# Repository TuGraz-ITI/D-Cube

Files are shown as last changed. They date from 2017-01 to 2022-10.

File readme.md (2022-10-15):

# D-Cube Benchmark #
The entire software stack for the ([public D-Cube instance](https://iti-testbed.tugraz.at/overview)) has been released as open-source as well and can be found ([here](https://github.com/TuGraz-ITI/D-Cube-Benchmark)). The initial documentation of the stack is avaialble ([here](https://tugraz-iti.github.io)).

# D-Cube Design #

D-Cube is published as open source hardware under [CC-BY-SA](license.md) ([online](https://creativecommons.org/licenses/by-sa/4.0/deed.en)).
D-Cube is a low-cost tool that allows to accurately profile the end-to-end delay, reliability, and power consumption, of low-power wireless sensor nodes, as well as to graphically visualize their evolution in real-time.
This tool has been used to set-up the EWSN 2016, 2017 and 2018 dependability competitions.
* [EWSN 2016 Dependability Competition (Graz, Austria)](http://ewsn2016.tugraz.at/cms/index.php?id=49)  
* [EWSN 2017 Dependability Competition (Uppsala, Sweden)](http://www.ewsn2017.org/dependability-competition1.html)
* [EWSN 2018 Dependability Competition (Madrid, Spain)](https://ewsn2018.networks.imdea.org/competition-program.html)
* [EWSN 2019 Dependability Competition (Beijing, China)](http://ewsn2019.thss.tsinghua.edu.cn/competition-scenario.html)

A scientific paper about D-Cube was published at the 14th International Conference on Embedded Wireless Systems and Networks (EWSN), and is available [here](http://www.carloalbertoboano.com/documents/boano17competition.pdf). 
An scientific paper describing D-Cube's binary patching capability and explaining how to use D-Cube to benchmark low-power wireless systems was published at the 1st International Workshop on Benchmarking Cyber-Physical Networks and Systems (CPSBench), and can be downloaded [here](http://www.carloalbertoboano.com/documents/schuss18benchmark.pdf).  
A set of slides giving a brief overview of D-Cube's capabilities and architecture can be found [here](http://www.carloalbertoboano.com/documents/D-Cube_overview.pdf).  

## D-Cube Hardware ##
The design files in this repository where used to fabricate the current iteration of D-Cube. The GPS module used is a Navspark-GL. For the complementary MOSFET a NTJD4105CT2G was chosen in the final design.

### The current version of the hardware (2.1) ###
The current version of the hardware supports multiple bi-directional GPIOs via isolation. It also adds support for PoE via a PEM1305 module. The aging navspark has been replaced with a more generic ublox neo footprint.

### The orignal version of the hardware (1.0) ###
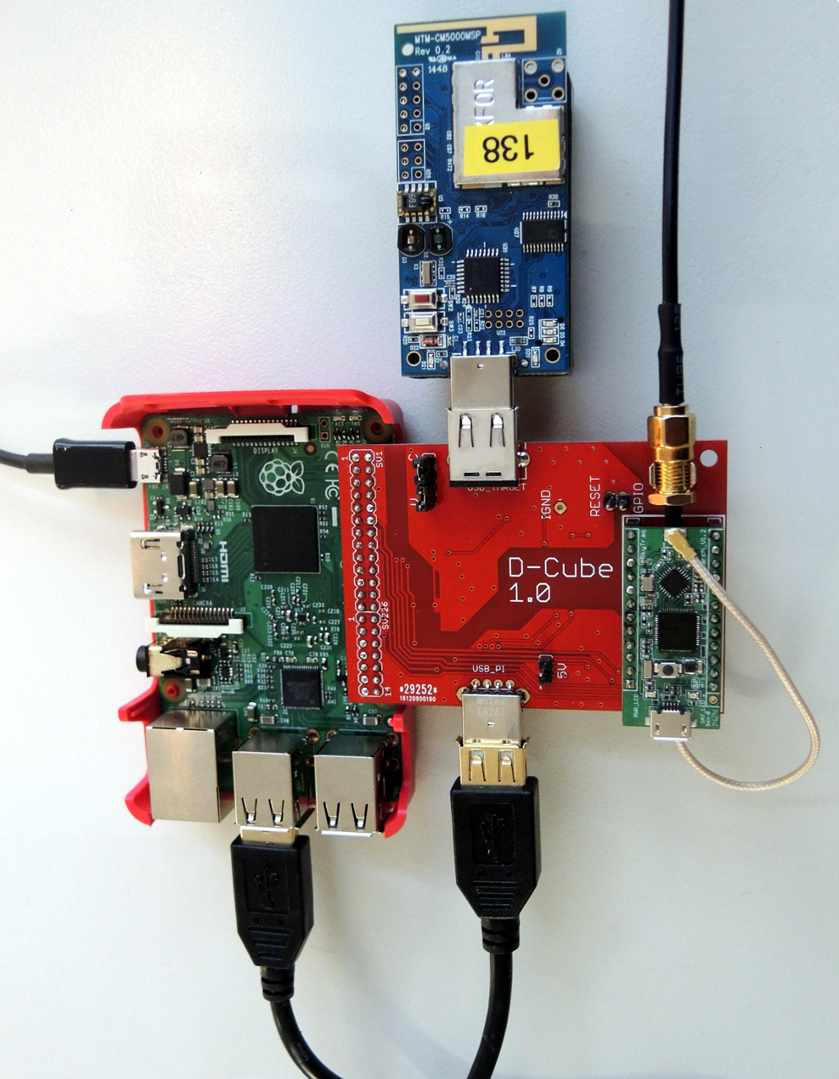
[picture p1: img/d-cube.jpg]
d-cube hardware revision 1.0


### The prototype used during EWSN 2016 ###
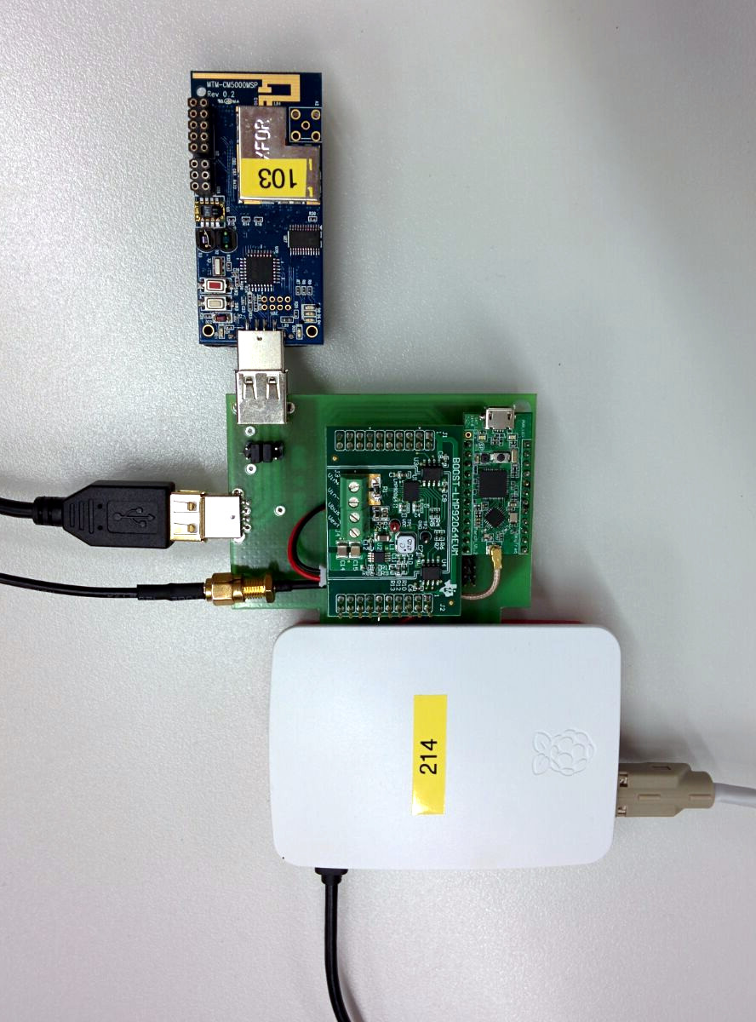
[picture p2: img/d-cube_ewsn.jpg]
d-cube hardware during ewsn2016


## D-Cube Software ##
The Software consists of two parts
* A task reading the ADC into a FIFO (on top of a real-time Linux kernel)
* A task reading the FIFO and writing it to the database (InfluxDB)

D-Cube contains a power switch circuit which controls the power before the DCDC isolator. A high signal on GPIO23 is required for the ADC and the target to be supplied with power. The gpio.sh file contains an example for this.

### Real-Time Linux ###
We used https://github.com/emlid/linux-rt-rpi but others should work fine

### Visualisation ###
InfluxDB has many frontends available, we used grafana (http://grafana.org/)

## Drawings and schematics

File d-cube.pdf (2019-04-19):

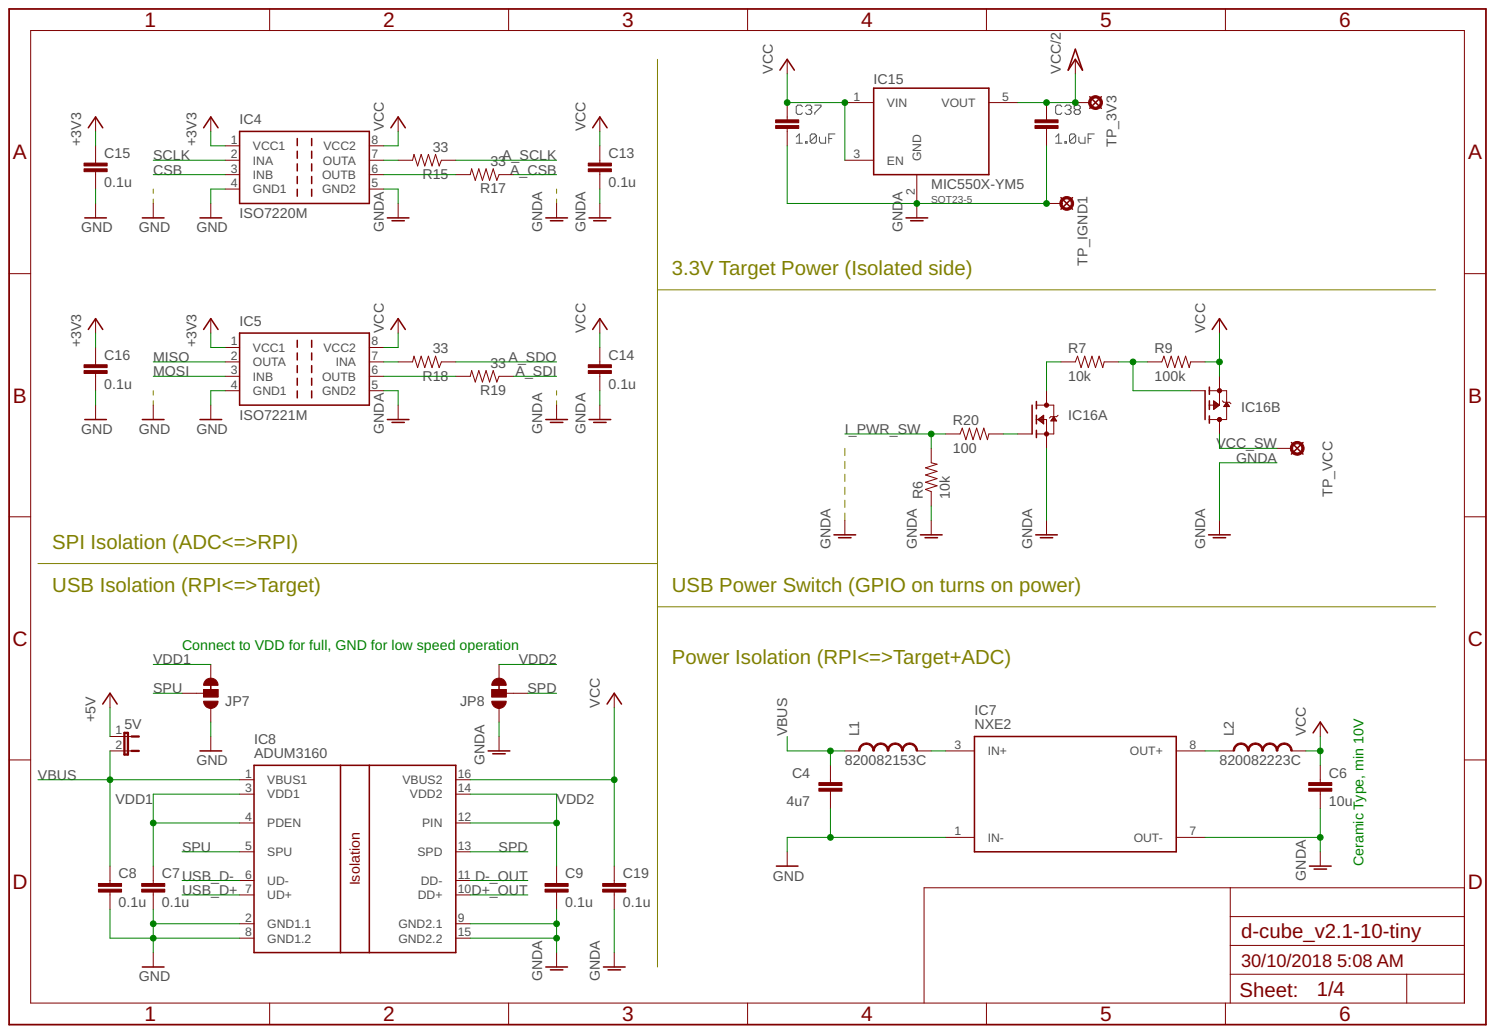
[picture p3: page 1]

3.3V Target Power (Isolated side)

SPI Isolation (ADC<=>RPI)

USB Isolation (RPI<=>Target)

USB Power Switch (GPIO on turns on power)

Connect to VDD for full, GND for low speed operation
VDD1

Power Isolation (RPI<=>Target+ADC)

USB_D- USB_D+ 7 | D+_OUT 10

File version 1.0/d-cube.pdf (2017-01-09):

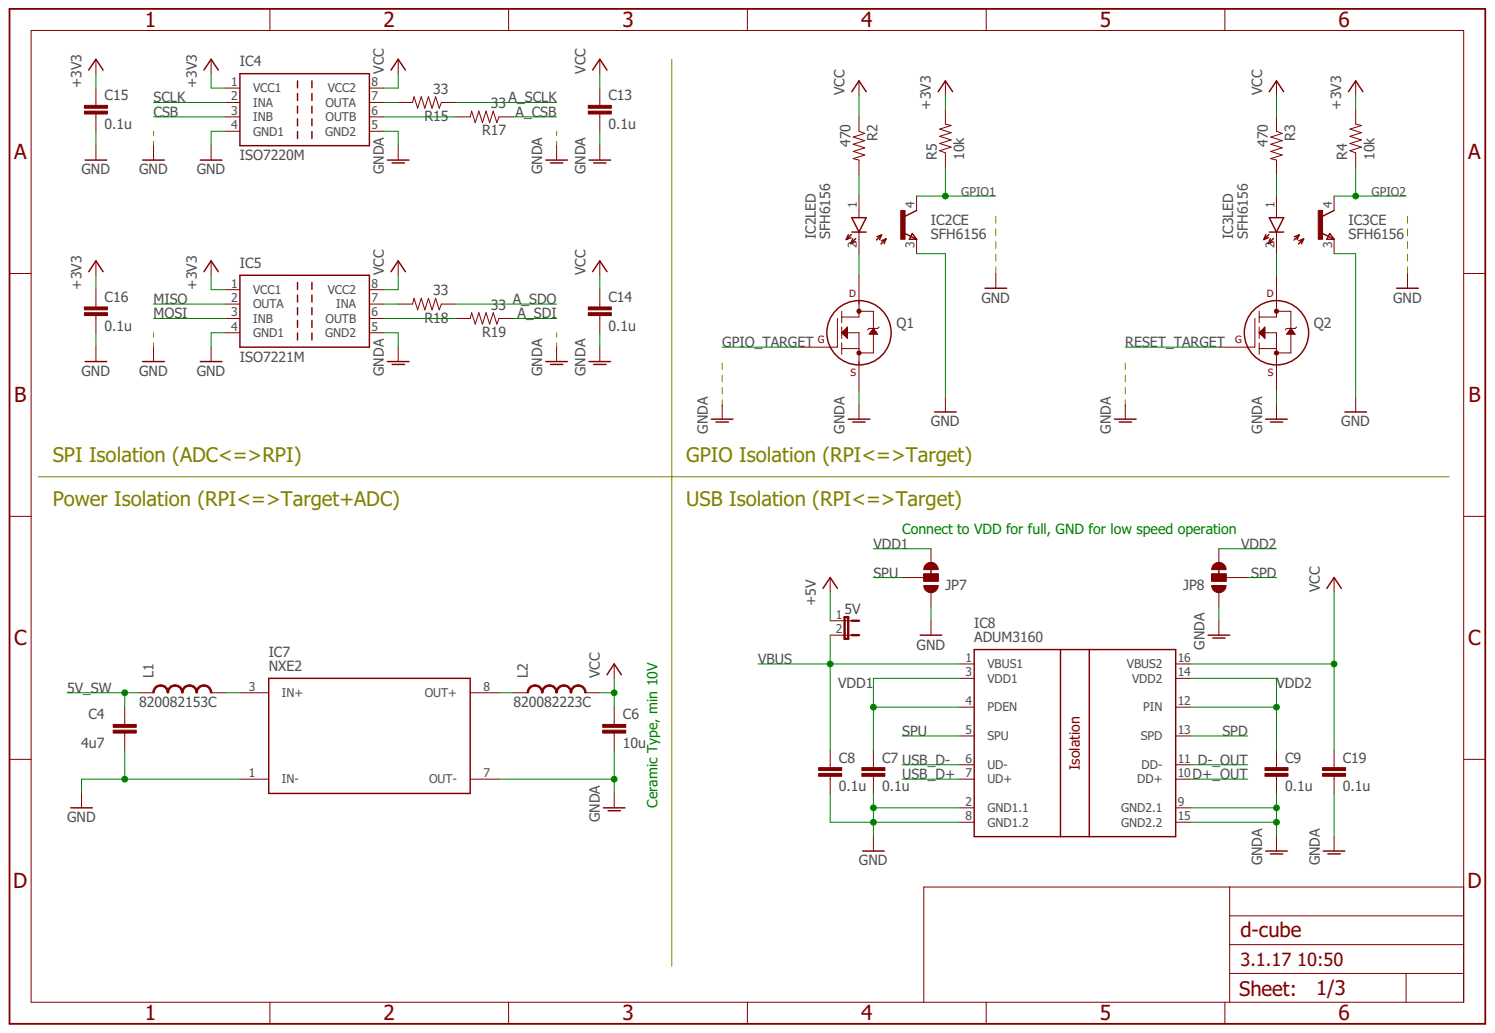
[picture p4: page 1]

VCC VCC GNDA GNDA

VCC GNDA

SPI Isolation (ADC<=>RPI)

GPIO Isolation (RPI<=>Target)

Power Isolation (RPI<=>Target+ADC)

USB Isolation (RPI<=>Target)

Connect to VDD for full, GND for low speed operation
VDD1

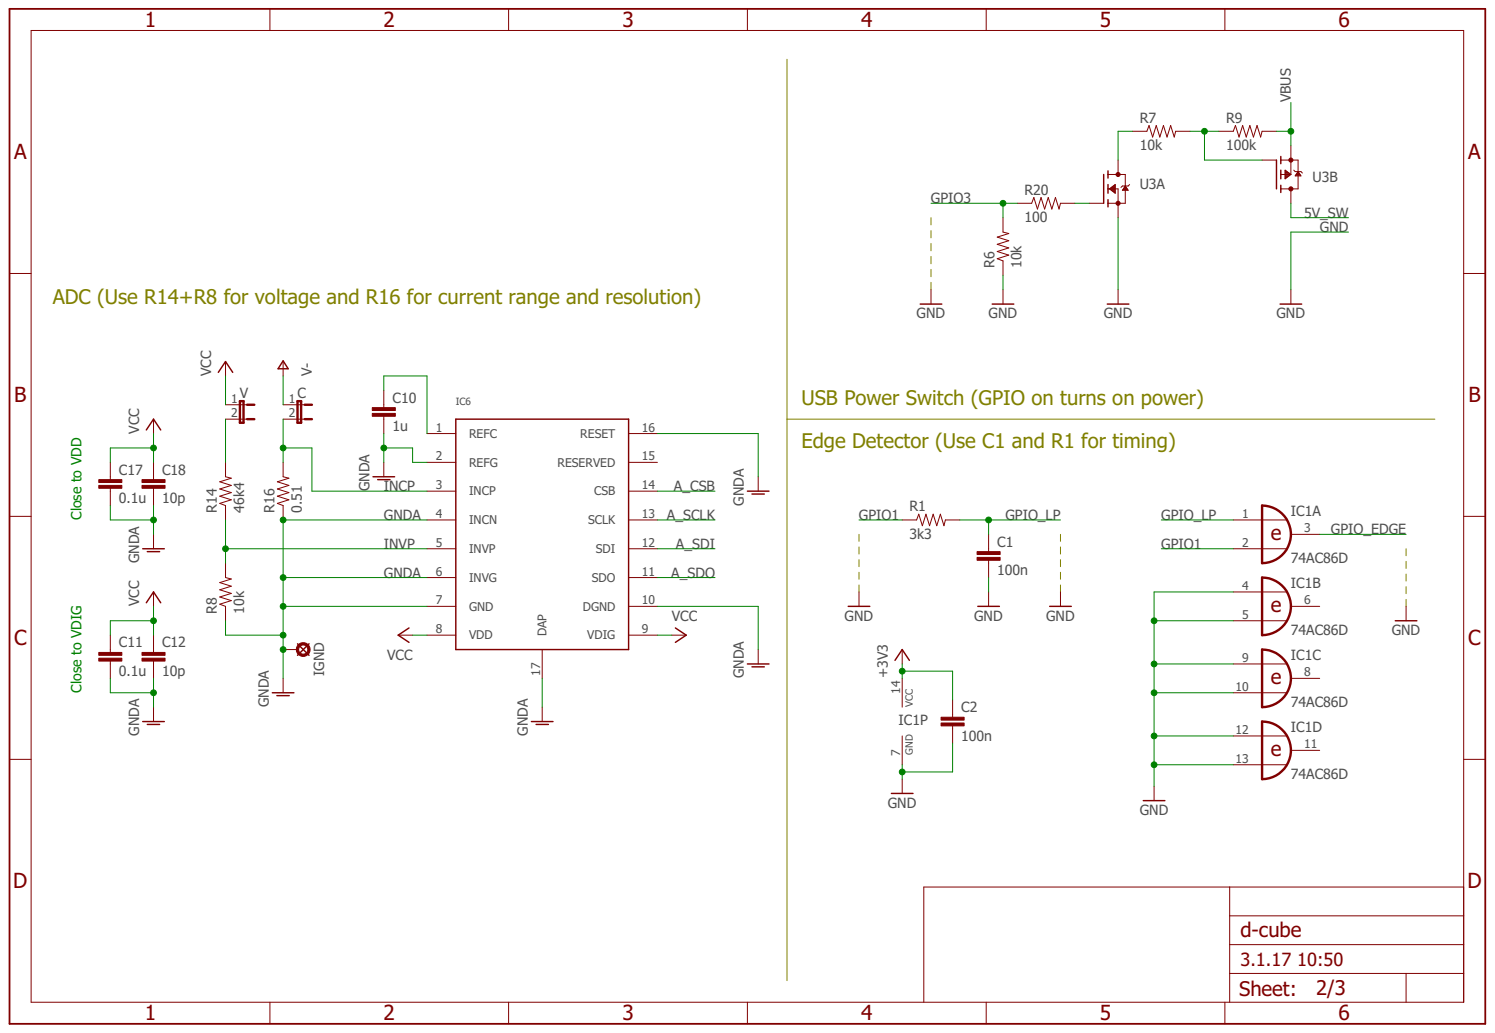
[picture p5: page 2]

ADC (Use R14+R8 for voltage and R16 for current range and resolution)

USB Power Switch (GPIO on turns on power)

Close to VDD Close to VDIG

Edge Detector (Use C1 and R1 for timing)

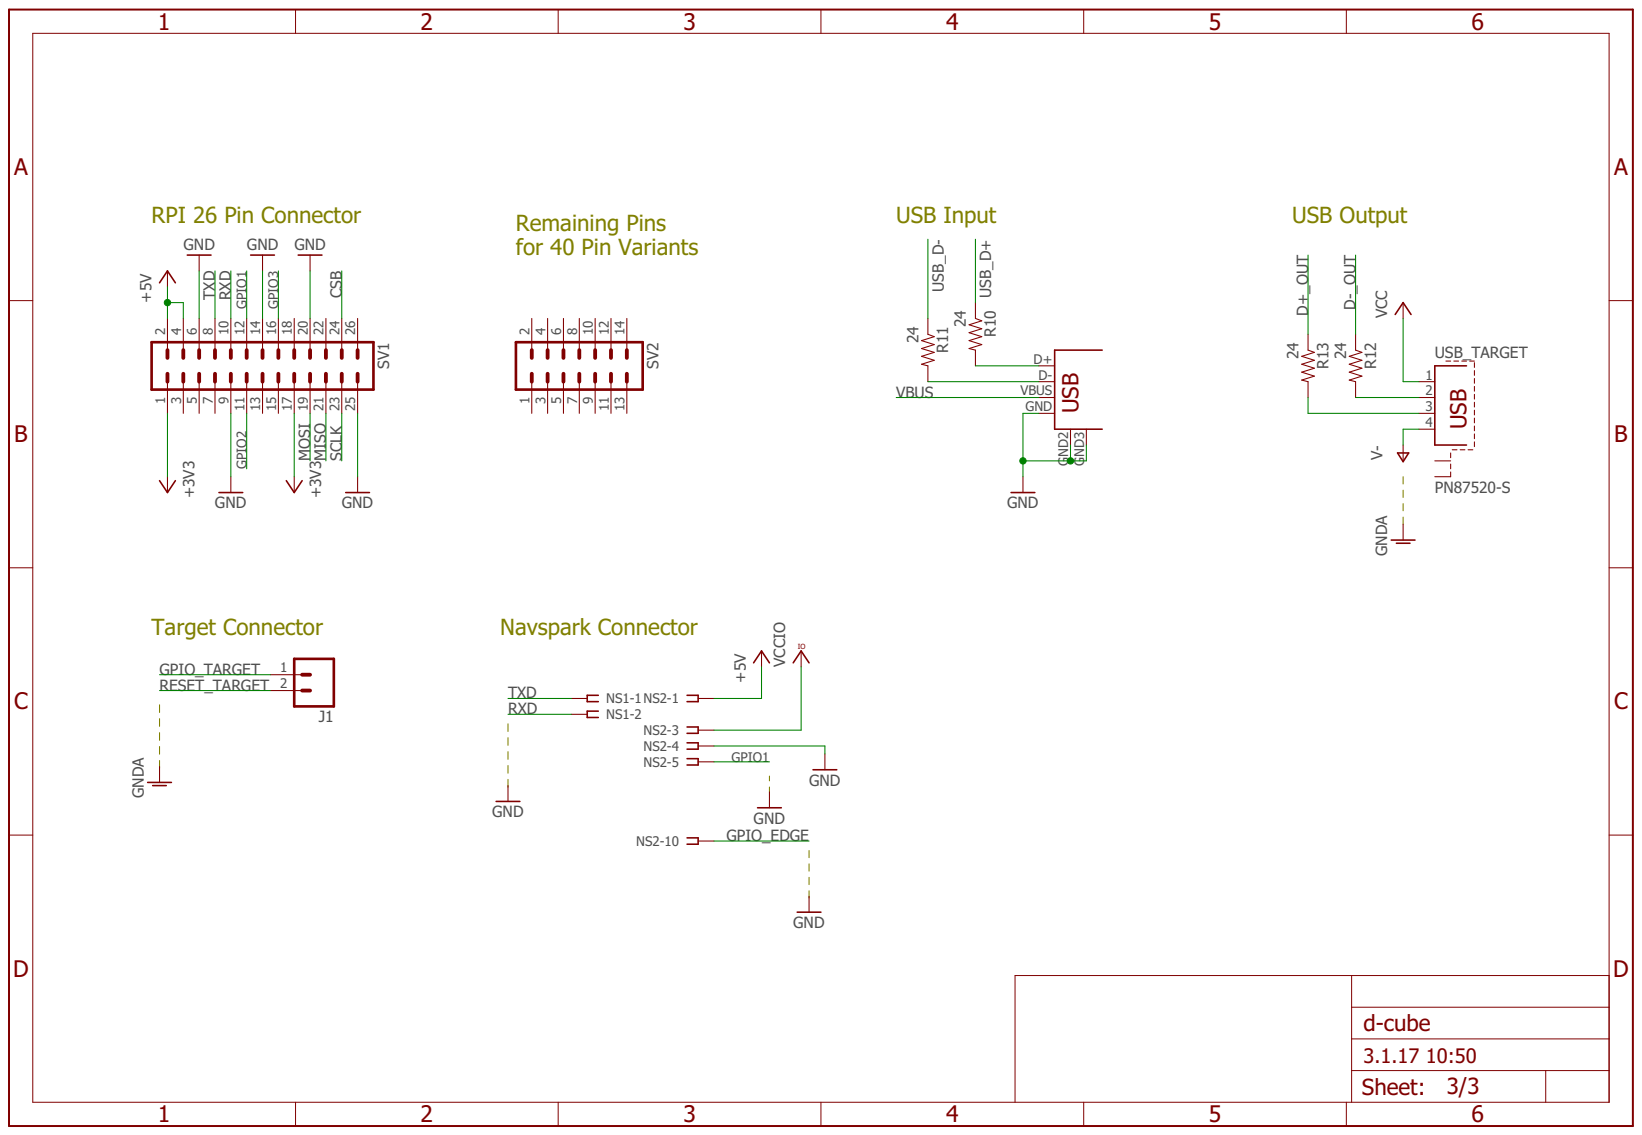
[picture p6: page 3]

CSB SCLK MISO MOSI

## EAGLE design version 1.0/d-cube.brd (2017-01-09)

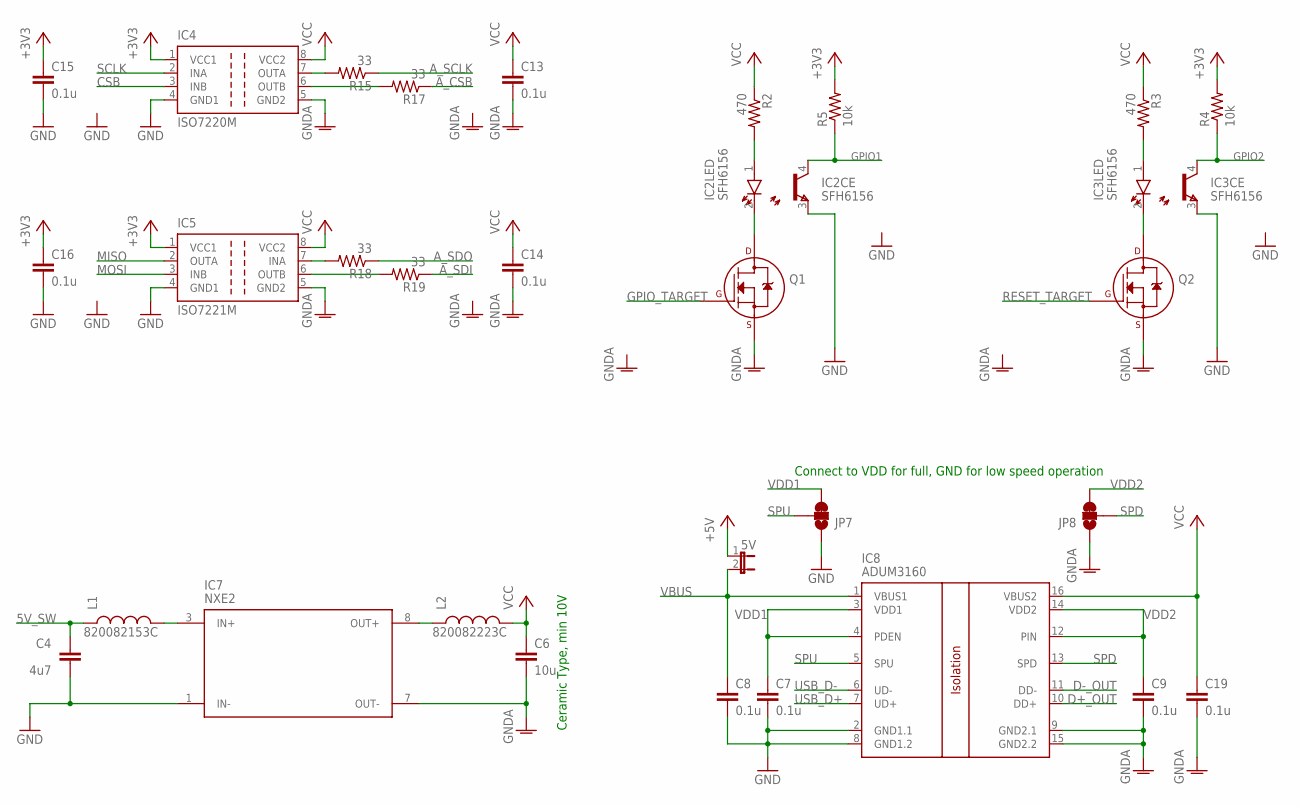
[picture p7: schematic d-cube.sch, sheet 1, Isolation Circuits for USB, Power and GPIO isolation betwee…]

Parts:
5V: JP1E; JP1
C4: 4u7; 0805
C6: 10u; 0805
C7, C8, C9, C13, C14, C15, C16, C19: 0.1u; 0805
IC2, IC3: SFH6156; SFH
IC4: ISO7220M; SO-08
IC5: ISO7221M; SO-08
IC7: NXE2
IC8: ADUM3160; SO-16W
JP7, JP8: JUMPER-PAD-3-2OF3_NC_BY_TRACE_LARGE; PAD-JUMPER-3-2OF3_NC_BY_TRACE_YES_SILK_LARGE
L1: 820082153C; 8200
L2: 820082223C; 8200
Q1, Q2: 2N7002_SOT23; SOT-23
R2, R3: 470; 0805
R4, R5: 10k; 0805
R15, R17, R18, R19: 33; 0805

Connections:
5V_SW: C4.1, L1.P$1 (1); also elsewhere on the board
+3V3: C15.1, C16.1, IC4.1 (VCC1), IC5.1 (VCC1), R4.2, R5.2; also elsewhere on the board
+5V: 5V.1; also elsewhere on the board
A_CSB: R17.1; also elsewhere on the board
A_SCLK: R15.1; also elsewhere on the board
A_SDI: R19.1; also elsewhere on the board
A_SDO: R18.1; also elsewhere on the board
CSB: IC4.3 (INB); also elsewhere on the board
D+_OUT: IC8.10 (DD+); also elsewhere on the board
D-_OUT: IC8.11 (DD-); also elsewhere on the board
GND: C4.2, C7.2, C8.2, C15.2, C16.2, IC2.3 (E), IC3.3 (E), IC4.4 (GND1), IC5.4 (GND1), IC7.1 (IN-), IC8.2 (GND1.1), IC8.8 (GND1.2), JP7.1; also elsewhere on the board
GNDA: C6.2, C9.2, C13.2, C14.2, C19.2, IC4.5 (GND2), IC5.5 (GND2), IC7.7 (OUT-), IC8.9 (GND2.1), IC8.15 (GND2.2), JP8.1, Q1.2 (S), Q2.2 (S); also elsewhere on the board
GPIO1: IC2.4 (C), R5.1; also elsewhere on the board
GPIO2: IC3.4 (C), R4.1; also elsewhere on the board
GPIO_TARGET: Q1.1 (G); also elsewhere on the board
MISO: IC5.2 (OUTA); also elsewhere on the board
MOSI: IC5.3 (INB); also elsewhere on the board
unnamed: IC7.3 (IN+), L1.P$2 (2)
unnamed: IC2.2 (K), Q1.3 (D)
unnamed: IC7.8 (OUT+), L2.P$1 (1)
unnamed: IC2.1 (A), R2.2
unnamed: IC3.1 (A), R3.2
unnamed: IC3.2 (K), Q2.3 (D)
unnamed: IC4.7 (OUTA), R15.2
unnamed: IC4.6 (OUTB), R17.2
unnamed: IC5.7 (INA), R18.2
unnamed: IC5.6 (OUTB), R19.2
RESET_TARGET: Q2.1 (G); also elsewhere on the board
SCLK: IC4.2 (INA); also elsewhere on the board
SPD: IC8.13 (SPD), JP8.2
SPU: IC8.5 (SPU), JP7.2
USB_D+: IC8.7 (UD+); also elsewhere on the board
USB_D-: IC8.6 (UD-); also elsewhere on the board
VBUS: 5V.2, C8.1, IC8.1 (VBUS1); also elsewhere on the board
VCC: C6.1, C13.1, C14.1, C19.1, IC4.8 (VCC2), IC5.8 (VCC2), IC8.16 (VBUS2), L2.P$2 (2), R2.1, R3.1; also elsewhere on the board
VDD1: C7.1, IC8.3 (VDD1), IC8.4 (PDEN), JP7.3
VDD2: C9.1, IC8.12 (PIN), IC8.14 (VDD2), JP8.3

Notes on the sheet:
Connect to VDD for full, GND for low speed operation
Ceramic Type, min 10V

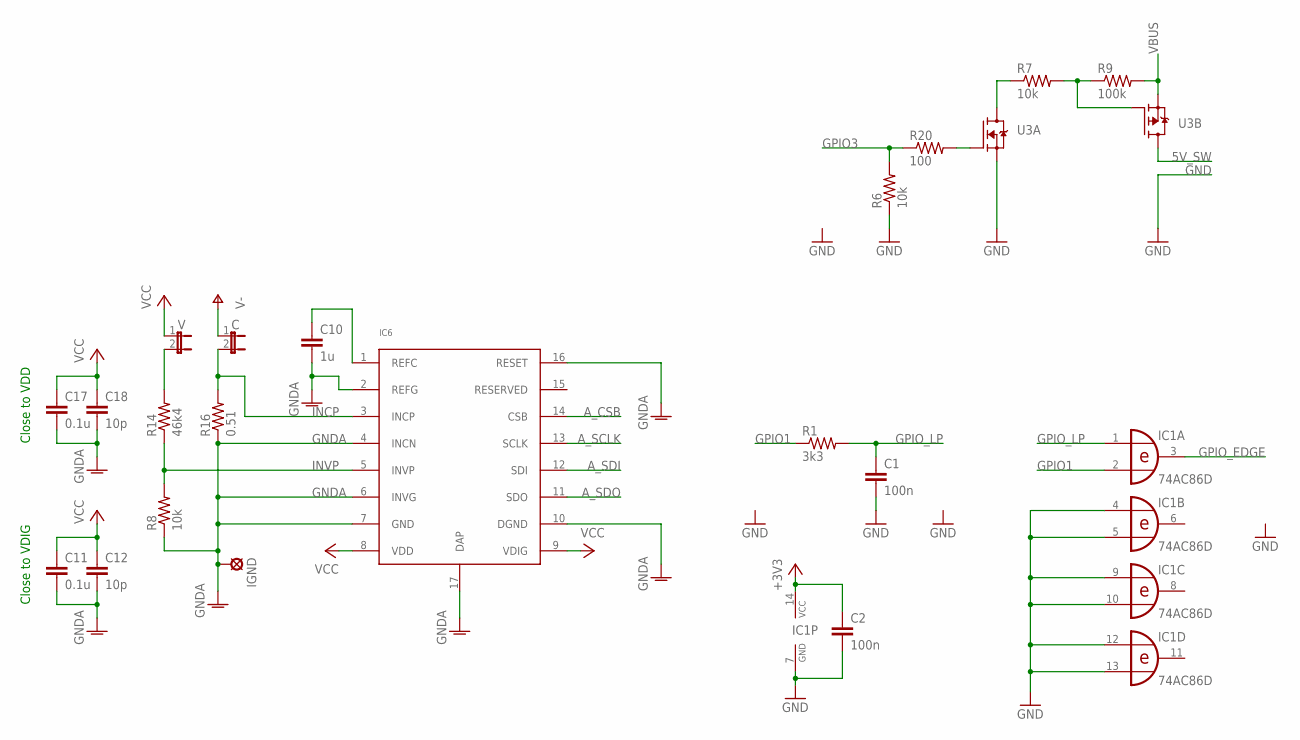
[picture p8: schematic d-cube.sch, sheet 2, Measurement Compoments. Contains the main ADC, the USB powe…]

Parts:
C: JP1E; JP1
C1, C2: 100n; 0805
C10: 1u; 0805
C11, C17: 0.1u; 0805
C12, C18: 10p; 0805
IC1: 74AC86D; SO14
IC6: LMP92064; WSON-16
IGND: LSP10
R1: 3k3; 0805
R6, R7, R8: 10k; 0805
R9: 100k; 0805
R14: 46k4; 0805
R16: 0.51; 1206
R20: 100; 0805
U3: COMPLEMENTARY; SOT-363
V: JP1E; JP1

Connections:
5V_SW: U3.3 (D); also elsewhere on the board
+3V3: C2.1, IC1.14 (VCC); also elsewhere on the board
A_CSB: IC6.14 (CSB); also elsewhere on the board
A_SCLK: IC6.13 (SCLK); also elsewhere on the board
A_SDI: IC6.12 (SDI); also elsewhere on the board
A_SDO: IC6.11 (SDO); also elsewhere on the board
GND: C1.2, C2.2, IC1.4 (I0), IC1.5 (I1), IC1.7 (GND), IC1.9 (I0), IC1.10 (I1), IC1.12 (I0), IC1.13 (I1), R6.1, U3.1 (S); also elsewhere on the board
GNDA: C10.2, C11.2, C12.2, C17.2, C18.2, IC6.2 (REFG), IC6.4 (INCN), IC6.6 (INVG), IC6.7 (GND), IC6.10 (DGND), IC6.16 (RESET), IC6.17 (DAP), IGND.MP, R8.1, R16.1; also elsewhere on the board
GPIO1: IC1.2 (I1), R1.1; also elsewhere on the board
GPIO3: R6.2, R20.1; also elsewhere on the board
GPIO_EDGE: IC1.3 (O); also elsewhere on the board
GPIO_LP: C1.1, IC1.1 (I0), R1.2
INCP: C.2, IC6.3 (INCP), R16.2
INVP: IC6.5 (INVP), R8.2, R14.1
unnamed: R20.2, U3.2 (G)
unnamed: R7.2, R9.1, U3.5 (G)
unnamed: R7.1, U3.6 (D)
unnamed: C10.1, IC6.1 (REFC)
unnamed: R14.2, V.2
V-: C.1; also elsewhere on the board
VBUS: R9.2, U3.4 (S); also elsewhere on the board
VCC: C11.1, C12.1, C17.1, C18.1, IC6.8 (VDD), IC6.9 (VDIG), V.1; also elsewhere on the board

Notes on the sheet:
Close to VDD
Close to VDIG

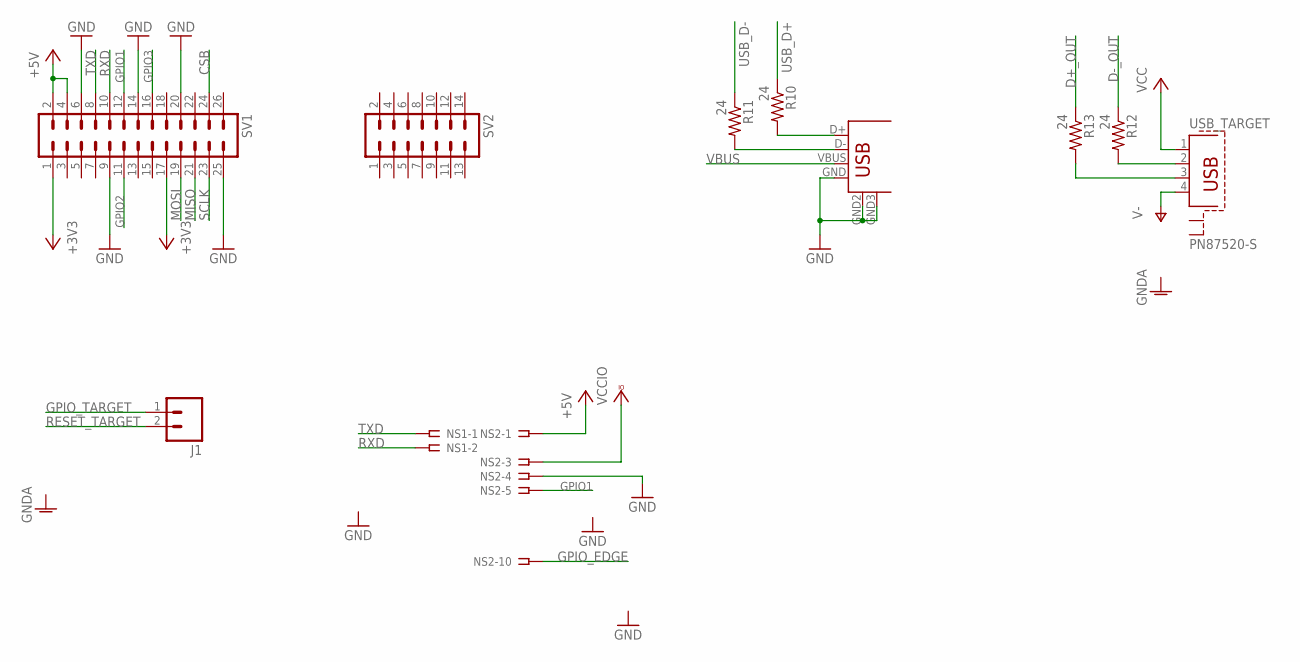
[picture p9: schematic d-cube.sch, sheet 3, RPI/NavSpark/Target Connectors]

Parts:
J1: M02PTH3; 1X02_LONGPADS
NS1, NS2: SSW-112-02-S-S
R10, R11, R12, R13: 24; 0805
SV1: MA13-2
SV2: MA07-2
USB_PI: USB+SHIELDUSB-A-H-S; USB-A-H
USB_TARGET: PN87520-S

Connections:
+3V3: SV1.1, SV1.17; also elsewhere on the board
+5V: NS2.1, SV1.2, SV1.4; also elsewhere on the board
CSB: SV1.24; also elsewhere on the board
D+_OUT: R13.1; also elsewhere on the board
D+_OUT_TERM: R13.2, USB_TARGET.3
D-_OUT: R12.1; also elsewhere on the board
D-_OUT_TERM: R12.2, USB_TARGET.2
GND: NS2.4, SV1.6, SV1.9, SV1.14, SV1.20, SV1.25, USB_PI.GND, USB_PI.GND2 (S1), USB_PI.GND3 (S2); also elsewhere on the board
GPIO1: NS2.5, SV1.12; also elsewhere on the board
GPIO2: SV1.11; also elsewhere on the board
GPIO3: SV1.16; also elsewhere on the board
GPIO_EDGE: NS2.10; also elsewhere on the board
GPIO_TARGET: J1.1; also elsewhere on the board
MISO: SV1.21; also elsewhere on the board
MOSI: SV1.19; also elsewhere on the board
RESET_TARGET: J1.2; also elsewhere on the board
RXD: NS1.2, SV1.10
SCLK: SV1.23; also elsewhere on the board
TXD: NS1.1, SV1.8
USB_D+: R10.1; also elsewhere on the board
USB_D+_TERM: R10.2, USB_PI.D+
USB_D-: R11.1; also elsewhere on the board
USB_D-_TERM: R11.2, USB_PI.D-
V-: USB_TARGET.4; also elsewhere on the board
VBUS: USB_PI.VBUS; also elsewhere on the board
VCC: USB_TARGET.1; also elsewhere on the board
VCCIO: NS2.3

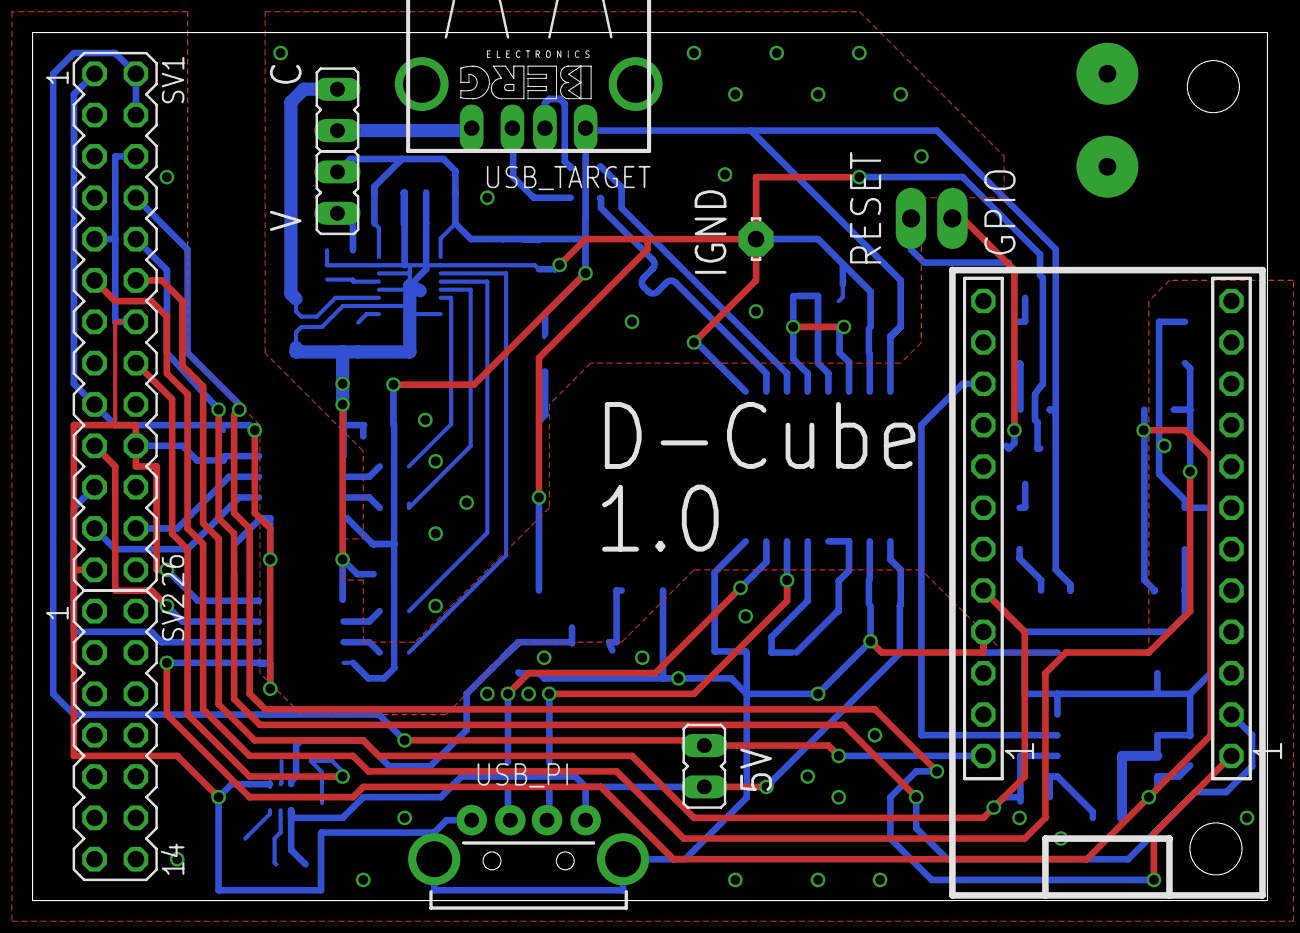
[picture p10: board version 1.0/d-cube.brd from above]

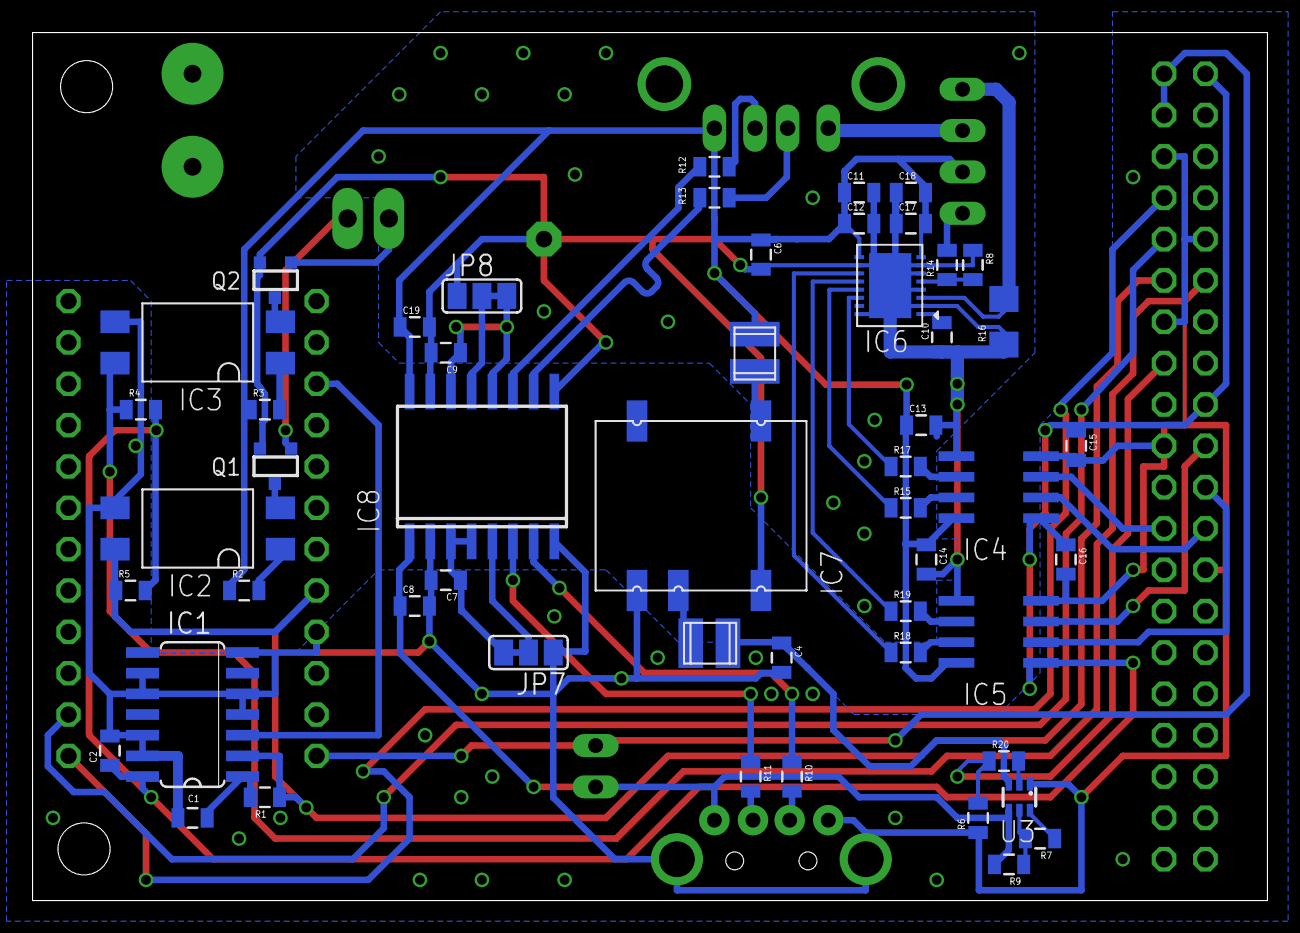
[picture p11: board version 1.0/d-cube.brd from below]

Board: 2 copper layers, 75.9 x 53.3 mm, 63 parts (52 on the bottom side), 54 nets.

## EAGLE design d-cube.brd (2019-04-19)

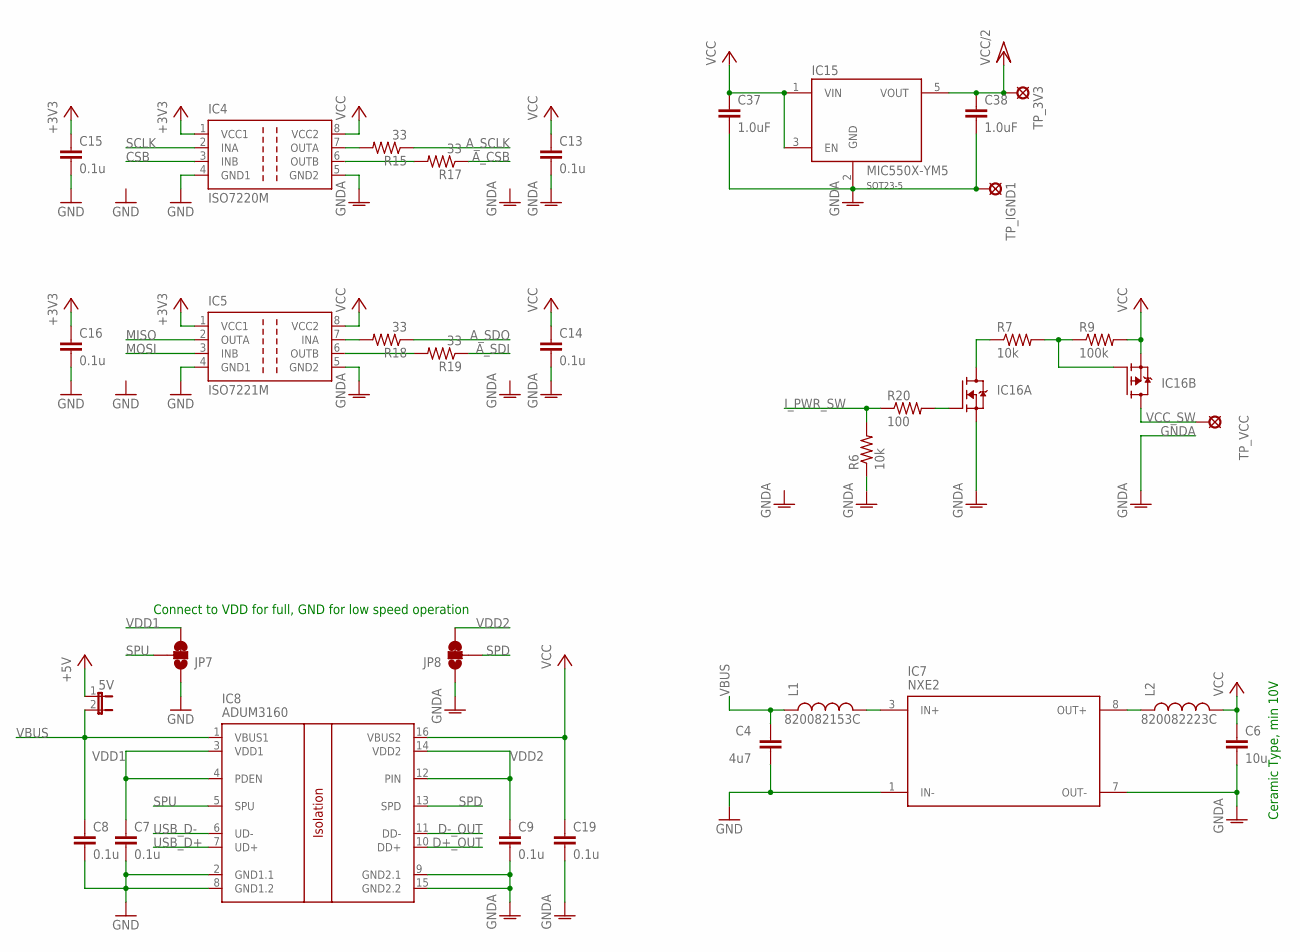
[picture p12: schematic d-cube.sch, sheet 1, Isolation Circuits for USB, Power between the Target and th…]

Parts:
5V: JP1E; JP1
C4: 4u7; 0805
C6: 10u; 0805
C7, C8, C9, C13, C14, C15, C16, C19: 0.1u; 0402-CAP
C37, C38: 1.0uF; 0805
IC4: ISO7220M; SO-08
IC5: ISO7221M; SO-08
IC7: NXE2
IC8: ADUM3160; SO-16W
IC15: MIC550X-YM5; SOT23-5-DBV
IC16: COMPLEMENTARY; SOT-363
JP7, JP8: JUMPER-PAD-3-2OF3_NC_BY_TRACE_LARGE; PAD-JUMPER-3-2OF3_NC_BY_TRACE_YES_SILK_LARGE
L1: 820082153C; 8200
L2: 820082223C; 8200
R6, R7: 10k; 0402-RES
R9: 100k; 0402-RES
R15, R17, R18, R19: 33; 0402-RES
R20: 100; 0402-RES
TP_3V3: LSP10
TP_IGND1: LSP10
TP_VCC: LSP10

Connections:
+3V3: C15.1, C16.1, IC4.1 (VCC1), IC5.1 (VCC1); also elsewhere on the board
+5V: 5V.1; also elsewhere on the board
A_CSB: R17.1; also elsewhere on the board
A_SCLK: R15.1; also elsewhere on the board
A_SDI: R19.1; also elsewhere on the board
A_SDO: R18.1; also elsewhere on the board
CSB: IC4.3 (INB); also elsewhere on the board
D+_OUT: IC8.10 (DD+); also elsewhere on the board
D-_OUT: IC8.11 (DD-); also elsewhere on the board
GND: C4.2, C7.2, C8.2, C15.2, C16.2, IC4.4 (GND1), IC5.4 (GND1), IC7.1 (IN-), IC8.2 (GND1.1), IC8.8 (GND1.2), JP7.1; also elsewhere on the board
GNDA: C6.2, C9.2, C13.2, C14.2, C19.2, C37.2, C38.2, IC4.5 (GND2), IC5.5 (GND2), IC7.7 (OUT-), IC8.9 (GND2.1), IC8.15 (GND2.2), IC15.2 (GND), IC16.1 (S), JP8.1, R6.1, TP_IGND1.MP; also elsewhere on the board
I_PWR_SW: R6.2, R20.1; also elsewhere on the board
MISO: IC5.2 (OUTA); also elsewhere on the board
MOSI: IC5.3 (INB); also elsewhere on the board
unnamed: IC7.3 (IN+), L1.P$2 (2)
unnamed: IC16.2 (G), R20.2
unnamed: IC16.5 (G), R7.2, R9.1
unnamed: IC7.8 (OUT+), L2.P$1 (1)
unnamed: IC16.6 (D), R7.1
unnamed: IC4.7 (OUTA), R15.2
unnamed: IC4.6 (OUTB), R17.2
unnamed: IC5.7 (INA), R18.2
unnamed: IC5.6 (OUTB), R19.2
SCLK: IC4.2 (INA); also elsewhere on the board
SPD: IC8.13 (SPD), JP8.2
SPU: IC8.5 (SPU), JP7.2
USB_D+: IC8.7 (UD+); also elsewhere on the board
USB_D-: IC8.6 (UD-); also elsewhere on the board
VBUS: 5V.2, C4.1, C8.1, IC8.1 (VBUS1), L1.P$1 (1); also elsewhere on the board
VCC: C6.1, C13.1, C14.1, C19.1, C37.1, IC4.8 (VCC2), IC5.8 (VCC2), IC8.16 (VBUS2), IC15.1 (VIN), IC15.3 (EN), IC16.4 (S), L2.P$2 (2), R9.2; also elsewhere on the board
VCC/2: C38.1, IC15.5 (VOUT), TP_3V3.MP; also elsewhere on the board
VCC_SW: IC16.3 (D), TP_VCC.MP; also elsewhere on the board
VDD1: C7.1, IC8.3 (VDD1), IC8.4 (PDEN), JP7.3
VDD2: C9.1, IC8.12 (PIN), IC8.14 (VDD2), JP8.3

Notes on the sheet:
Connect to VDD for full, GND for low speed operation
Ceramic Type, min 10V

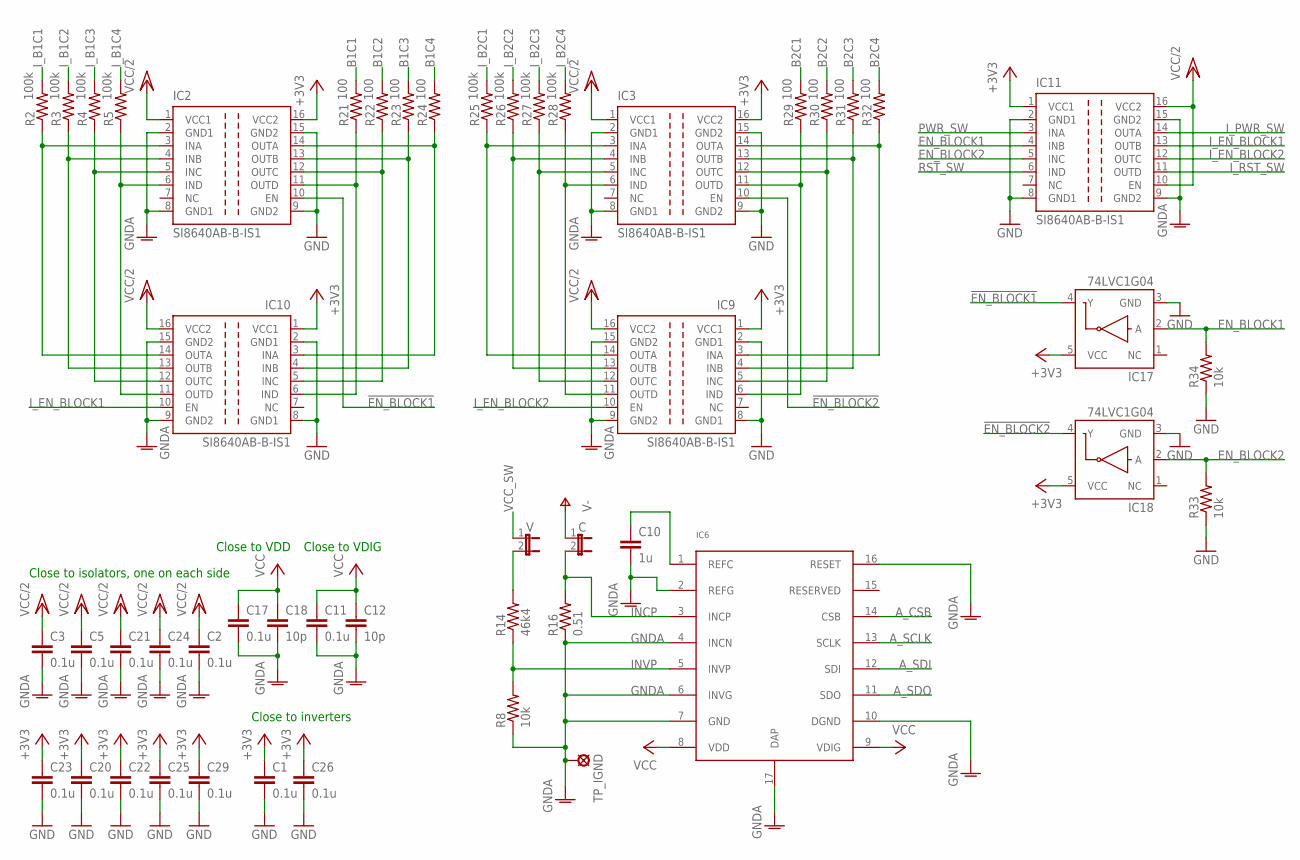
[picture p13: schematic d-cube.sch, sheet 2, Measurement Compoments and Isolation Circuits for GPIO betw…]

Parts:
C: JP1E; JP1
C1, C2, C3, C5, C11, C17, C20, C21, C22, C23, C24, C25, C26, C29: 0.1u; 0402-CAP
C10: 1u; 0402-CAP
C12, C18: 10p; 0402-CAP
IC2, IC3, IC9, IC10, IC11: SI8640AB-B-IS1; SO-16
IC6: LMP92064; WSON-16
IC17, IC18: 74LVC1G04; SOT353
R2, R3, R4, R5, R25, R26, R27, R28: 100k; 0402-RES
R8: 10k; 0805
R14: 46k4; 0805
R16: 0.51; 1206
R21, R22, R23, R24, R29, R30, R31, R32: 100; 0402-RES
R33, R34: 10k; 0402-RES
TP_IGND: LSP10
V: JP1E; JP1

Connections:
!EN_BLOCK1: IC2.10 (EN), IC17.4 (Y)
!EN_BLOCK2: IC3.10 (EN), IC18.4 (Y)
+3V3: C1.1, C20.1, C22.1, C23.1, C25.1, C26.1, C29.1, IC2.16 (VCC2), IC3.16 (VCC2), IC9.1 (VCC1), IC10.1 (VCC1), IC11.1 (VCC1), IC17.5 (VCC), IC18.5 (VCC); also elsewhere on the board
A_CSB: IC6.14 (CSB); also elsewhere on the board
A_SCLK: IC6.13 (SCLK); also elsewhere on the board
A_SDI: IC6.12 (SDI); also elsewhere on the board
A_SDO: IC6.11 (SDO); also elsewhere on the board
B1C1: R21.2; also elsewhere on the board
B1C2: R22.2; also elsewhere on the board
B1C3: R23.2; also elsewhere on the board
B1C4: R24.2; also elsewhere on the board
B2C1: R29.2; also elsewhere on the board
B2C2: R30.2; also elsewhere on the board
B2C3: R31.2; also elsewhere on the board
B2C4: R32.2; also elsewhere on the board
EN_BLOCK1: IC11.4 (INB), IC17.2 (A), R34.2; also elsewhere on the board
EN_BLOCK2: IC11.5 (INC), IC18.2 (A), R33.2; also elsewhere on the board
GND: C1.2, C20.2, C22.2, C23.2, C25.2, C26.2, C29.2, IC2.9 (GND2), IC2.15 (GND2), IC3.9 (GND2), IC3.15 (GND2), IC9.2 (GND1), IC9.8 (GND1), IC10.2 (GND1), IC10.8 (GND1), IC11.2 (GND1), IC11.8 (GND1), IC17.3 (GND), IC18.3 (GND), R33.1, R34.1; also elsewhere on the board
GNDA: C2.2, C3.2, C5.2, C10.2, C11.2, C12.2, C17.2, C18.2, C21.2, C24.2, IC2.2 (GND1), IC2.8 (GND1), IC3.2 (GND1), IC3.8 (GND1), IC6.2 (REFG), IC6.4 (INCN), IC6.6 (INVG), IC6.7 (GND), IC6.10 (DGND), IC6.16 (RESET), IC6.17 (DAP), IC9.9 (GND2), IC9.15 (GND2), IC10.9 (GND2), IC10.15 (GND2), IC11.9 (GND2), IC11.15 (GND2), R8.1, R16.1, TP_IGND.MP; also elsewhere on the board
INCP: C.2, IC6.3 (INCP), R16.2
INVP: IC6.5 (INVP), R8.2, R14.1
I_B1C1: R2.2; also elsewhere on the board
I_B1C2: R3.2; also elsewhere on the board
I_B1C3: R4.2; also elsewhere on the board
I_B1C4: R5.2; also elsewhere on the board
I_B2C1: R25.2; also elsewhere on the board
I_B2C2: R26.2; also elsewhere on the board
I_B2C3: R27.2; also elsewhere on the board
I_B2C4: R28.2; also elsewhere on the board
I_EN_BLOCK1: IC10.10 (EN), IC11.13 (OUTB)
I_EN_BLOCK2: IC9.10 (EN), IC11.12 (OUTC)
I_PWR_SW: IC11.14 (OUTA); also elsewhere on the board
I_RST_SW: IC11.11 (OUTD); also elsewhere on the board
unnamed: IC2.3 (INA), IC10.14 (OUTA), R2.1
unnamed: IC2.14 (OUTA), IC10.3 (INA), R24.1
unnamed: IC2.13 (OUTB), IC10.4 (INB), R23.1
unnamed: IC2.12 (OUTC), IC10.5 (INC), R22.1
unnamed: IC3.3 (INA), IC9.14 (OUTA), R25.1
unnamed: IC2.6 (IND), IC10.11 (OUTD), R5.1
unnamed: IC2.5 (INC), IC10.12 (OUTC), R4.1
unnamed: IC2.4 (INB), IC10.13 (OUTB), R3.1
unnamed: C10.1, IC6.1 (REFC)
unnamed: IC2.11 (OUTD), IC10.6 (IND), R21.1
unnamed: R14.2, V.2
unnamed: IC3.6 (IND), IC9.11 (OUTD), R28.1
unnamed: IC3.5 (INC), IC9.12 (OUTC), R27.1
unnamed: IC3.4 (INB), IC9.13 (OUTB), R26.1
unnamed: IC3.14 (OUTA), IC9.3 (INA), R32.1
unnamed: IC3.13 (OUTB), IC9.4 (INB), R31.1
unnamed: IC3.12 (OUTC), IC9.5 (INC), R30.1
unnamed: IC3.11 (OUTD), IC9.6 (IND), R29.1
PWR_SW: IC11.3 (INA); also elsewhere on the board
RST_SW: IC11.6 (IND); also elsewhere on the board
V-: C.1; also elsewhere on the board
VCC: C11.1, C12.1, C17.1, C18.1, IC6.8 (VDD), IC6.9 (VDIG); also elsewhere on the board
VCC/2: C2.1, C3.1, C5.1, C21.1, C24.1, IC2.1 (VCC1), IC3.1 (VCC1), IC9.16 (VCC2), IC10.16 (VCC2), IC11.10 (EN), IC11.16 (VCC2); also elsewhere on the board
VCC_SW: V.1; also elsewhere on the board

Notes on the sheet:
Close to inverters
Close to isolators, one on each side
Close to VDD
Close to VDIG

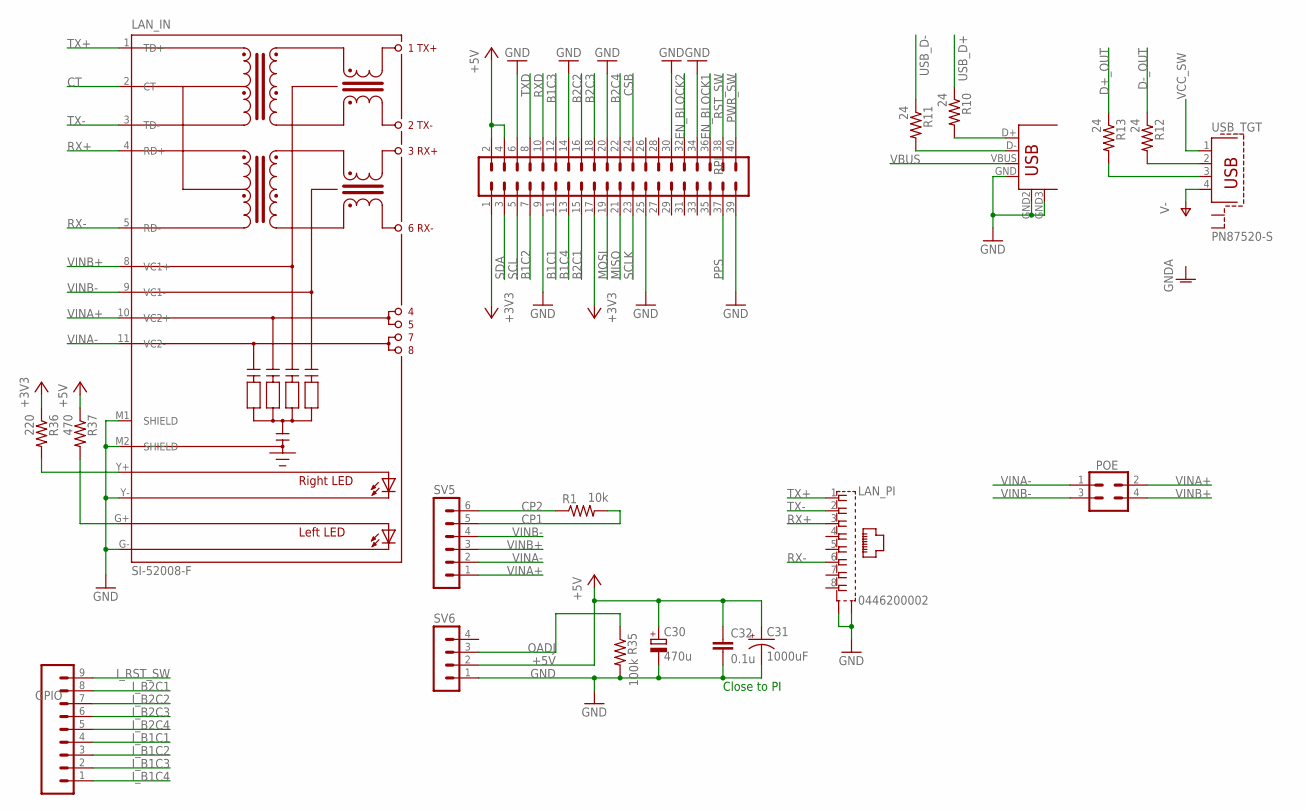
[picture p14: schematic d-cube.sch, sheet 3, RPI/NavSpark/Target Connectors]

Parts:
C30: 470u; CT7343
C31: 1000uF; PANASONIC_G
C32: 0.1u; 0805
GPIO: CONN_09NO_SILK; 1X09_NO_SILK
LAN_IN: SI-52008-F; POE
LAN_PI: 0446200002
POE: CONN_02X2; 2X02_NO_SILK
R1: 10k; 0402-RES
R10, R11, R12, R13: 24; 0402-RES
R35: 100k; 0402-RES
R36: 220; 0402-RES
R37: 470; 0402-RES
RPI: MA20-2
SV5: MA06-1
SV6: MA04-1
USB_PI: USB+SHIELDUSB-A-H-S; USB-A-H
USB_TGT: PN87520-S

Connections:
+3V3: R36.1, RPI.1, RPI.17; also elsewhere on the board
+5V: C30.+, C31.+, C32.1, R37.1, RPI.2, RPI.4, SV6.2; also elsewhere on the board
B1C1: RPI.11; also elsewhere on the board
B1C2: RPI.7; also elsewhere on the board
B1C3: RPI.12; also elsewhere on the board
B1C4: RPI.13; also elsewhere on the board
B2C1: RPI.15; also elsewhere on the board
B2C2: RPI.16; also elsewhere on the board
B2C3: RPI.18; also elsewhere on the board
B2C4: RPI.22; also elsewhere on the board
CP1: R1.2, SV5.5
CP2: R1.1, SV5.6
CSB: RPI.24; also elsewhere on the board
CT: LAN_IN.2 (CT)
D+_OUT: R13.1; also elsewhere on the board
D+_OUT_TERM: R13.2, USB_TGT.3
D-_OUT: R12.1; also elsewhere on the board
D-_OUT_TERM: R12.2, USB_TGT.2
EN_BLOCK1: RPI.36; also elsewhere on the board
EN_BLOCK2: RPI.32; also elsewhere on the board
GND: C30.-, C31.-, C32.2, LAN_IN.G- (C-L), LAN_IN.M1 (SHIELD), LAN_IN.M2 (SHIELD), LAN_IN.Y- (C-R), LAN_PI.S@1 (S1), LAN_PI.S@2 (S2), R35.2, RPI.6, RPI.9, RPI.14, RPI.20, RPI.25, RPI.30, RPI.34, RPI.39, SV6.1, USB_PI.GND, USB_PI.GND2 (S1), USB_PI.GND3 (S2); also elsewhere on the board
I_B1C1: GPIO.4; also elsewhere on the board
I_B1C2: GPIO.3; also elsewhere on the board
I_B1C3: GPIO.2; also elsewhere on the board
I_B1C4: GPIO.1; also elsewhere on the board
I_B2C1: GPIO.8; also elsewhere on the board
I_B2C2: GPIO.7; also elsewhere on the board
I_B2C3: GPIO.6; also elsewhere on the board
I_B2C4: GPIO.5; also elsewhere on the board
I_RST_SW: GPIO.9; also elsewhere on the board
MISO: RPI.21; also elsewhere on the board
MOSI: RPI.19; also elsewhere on the board
unnamed: LAN_IN.Y+ (A-R), R36.2
unnamed: LAN_IN.G+ (A-L), R37.2
OADJ: R35.1, SV6.3
PPS: RPI.37; also elsewhere on the board
PWR_SW: RPI.40; also elsewhere on the board
RST_SW: RPI.38; also elsewhere on the board
RX+: LAN_IN.4 (RD+), LAN_PI.3
RX-: LAN_IN.5 (RD-), LAN_PI.6
RXD: RPI.10; also elsewhere on the board
SCL: RPI.5; also elsewhere on the board
SCLK: RPI.23; also elsewhere on the board
SDA: RPI.3; also elsewhere on the board
TX+: LAN_IN.1 (TD+), LAN_PI.1
TX-: LAN_IN.3 (TD-), LAN_PI.2
TXD: RPI.8; also elsewhere on the board
USB_D+: R10.1; also elsewhere on the board
USB_D+_TERM: R10.2, USB_PI.D+
USB_D-: R11.1; also elsewhere on the board
USB_D-_TERM: R11.2, USB_PI.D-
V-: USB_TGT.4; also elsewhere on the board
VBUS: USB_PI.VBUS; also elsewhere on the board
VCC_SW: USB_TGT.1; also elsewhere on the board
VINA+: LAN_IN.10 (VC2+), POE.2, SV5.1
VINA-: LAN_IN.11 (VC2-), POE.1, SV5.2
VINB+: LAN_IN.8 (VC1+), POE.4, SV5.3
VINB-: LAN_IN.9 (VC1-), POE.3, SV5.4

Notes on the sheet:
Close to PI

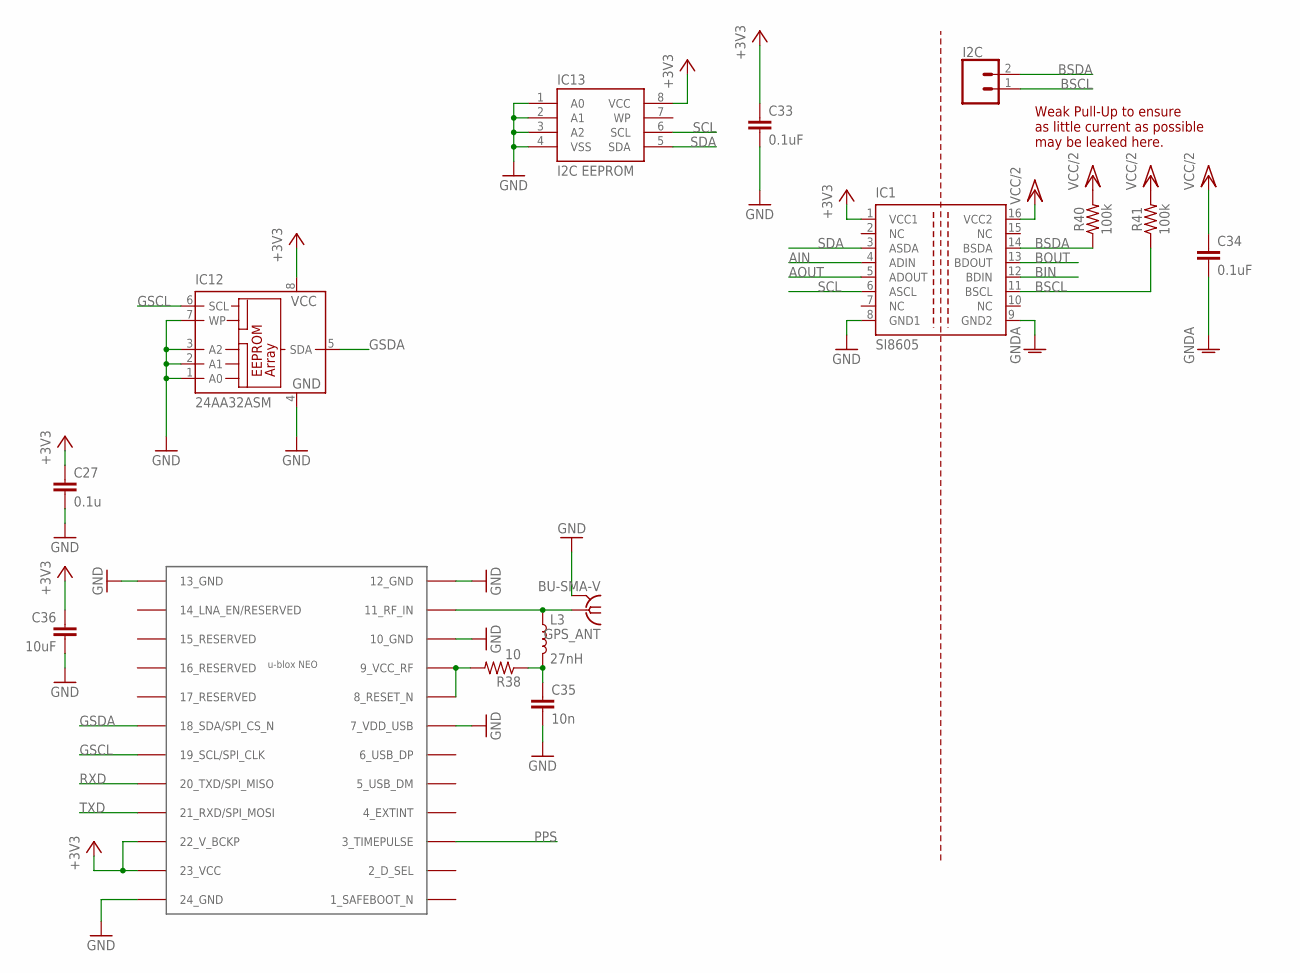
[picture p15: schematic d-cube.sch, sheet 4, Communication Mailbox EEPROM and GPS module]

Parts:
C27: 0.1u; 0402-CAP
C33, C34: 0.1uF; 0402
C35: 10n; 0805
C36: 10uF; 0805
GPS_ANT: BU-SMA-V
I2C: CONN_021X02_NO_SILK; 1X02_NO_SILK
IC1: SI8605; SO-16
IC12: 24AA32ASM; SO-08M
IC13: I2C EEPROM; SO08-EIAJ
IC14: NEO-M8
L3: 27nH; 0402
R38: 10; 0402-RES
R40, R41: 100k; 0402

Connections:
+3V3: C27.1, C33.1, C36.1, IC1.1 (VCC1), IC12.8 (VCC), IC13.8 (VCC), IC14.22 (22_V_BCKP), IC14.23 (23_VCC); also elsewhere on the board
AIN: IC1.4 (ADIN)
AOUT: IC1.5 (ADOUT)
BIN: IC1.12 (BDIN)
BOUT: IC1.13 (BDOUT)
BSCL: I2C.1, IC1.11 (BSCL), R41.1
BSDA: I2C.2, IC1.14 (BSDA), R40.1
GND: C27.2, C33.2, C35.2, C36.2, GPS_ANT.2 (GND), GPS_ANT.3 (GND), GPS_ANT.4 (GND), GPS_ANT.5 (GND), IC1.8 (GND1), IC12.1 (A0), IC12.2 (A1), IC12.3 (A2), IC12.4 (GND), IC12.7 (WP), IC13.1 (A0), IC13.2 (A1), IC13.3 (A2), IC13.4 (VSS), IC14.7 (7_VDD_USB), IC14.10 (10_GND), IC14.12 (12_GND), IC14.13 (13_GND), IC14.24 (24_GND); also elsewhere on the board
GNDA: C34.2, IC1.9 (GND2); also elsewhere on the board
GPS_SIG: GPS_ANT.1, IC14.11 (11_RF_IN), L3.1
GSCL: IC12.6 (SCL), IC14.19 (19_SCL/SPI_CLK)
GSDA: IC12.5 (SDA), IC14.18 (18_SDA/SPI_CS_N)
unnamed: IC14.8 (8_RESET_N), IC14.9 (9_VCC_RF), R38.2
unnamed: C35.1, L3.2, R38.1
PPS: IC14.3 (3_TIMEPULSE); also elsewhere on the board
RXD: IC14.20 (20_TXD/SPI_MISO); also elsewhere on the board
SCL: IC1.6 (ASCL), IC13.6 (SCL); also elsewhere on the board
SDA: IC1.3 (ASDA), IC13.5 (SDA); also elsewhere on the board
TXD: IC14.21 (21_RXD/SPI_MOSI); also elsewhere on the board
VCC/2: C34.1, IC1.16 (VCC2), R40.2, R41.2; also elsewhere on the board

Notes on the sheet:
Weak Pull-Up to ensure as little current as possible may be leaked here.

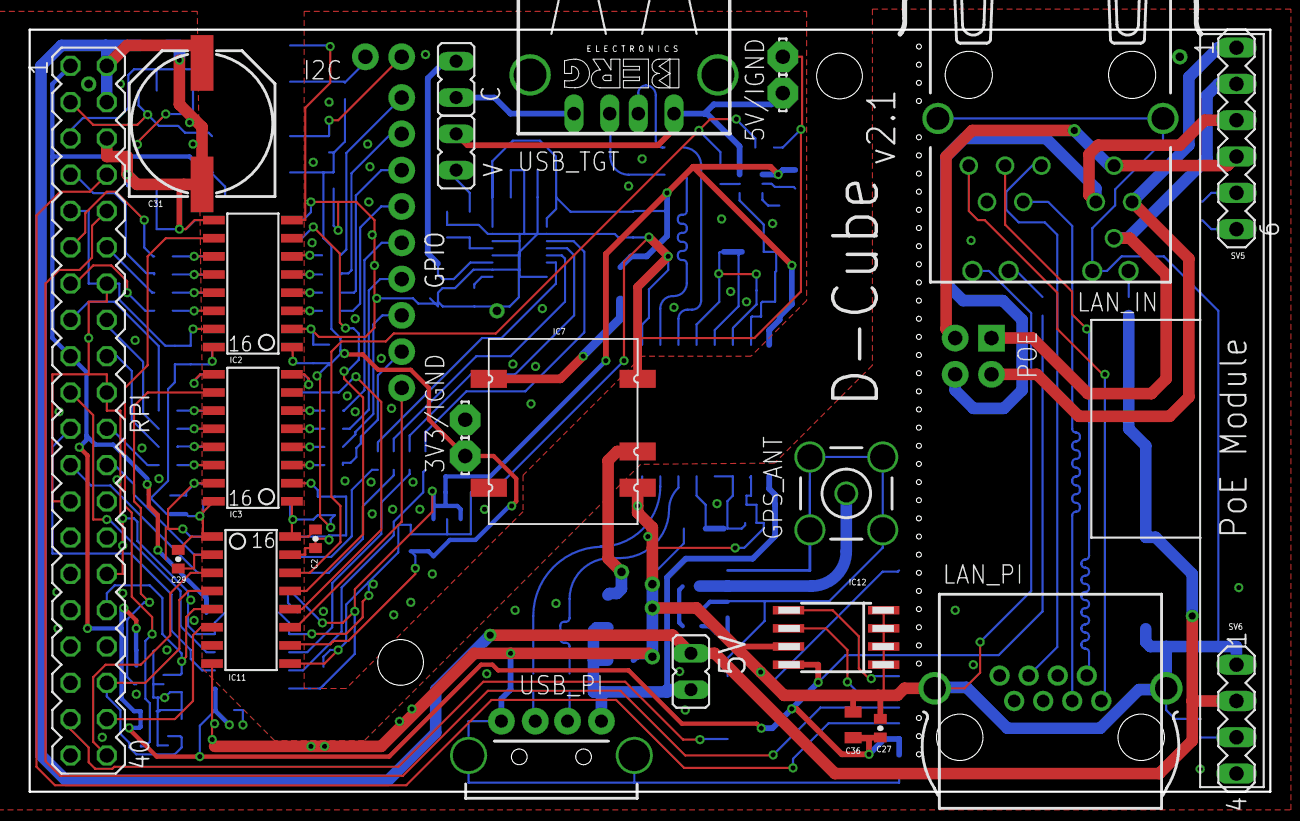
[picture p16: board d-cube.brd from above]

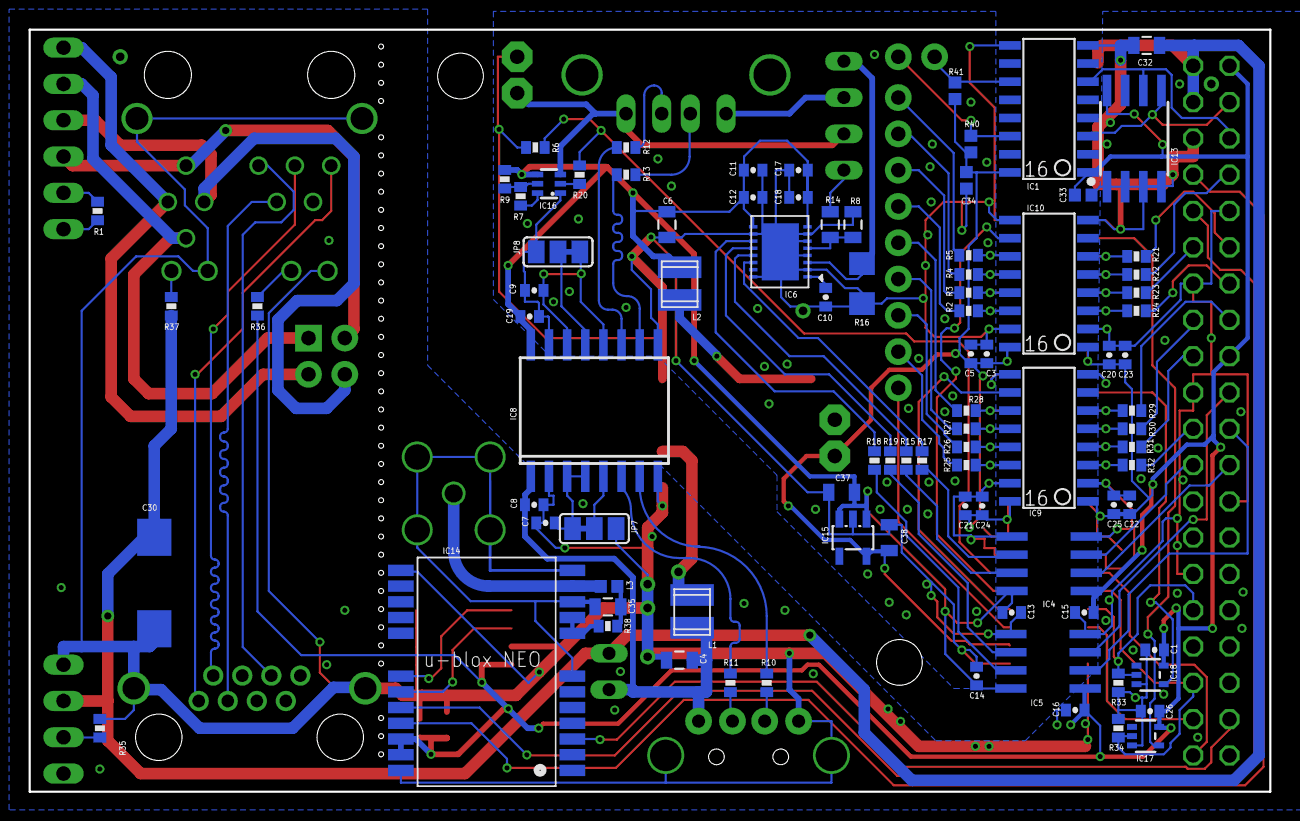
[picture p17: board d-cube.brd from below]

Board: 2 copper layers, 86.8 x 53.3 mm, 120 parts (91 on the bottom side), 109 nets.

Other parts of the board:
U$1, U$2: TU-LOGO-SMALL

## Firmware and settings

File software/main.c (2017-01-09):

#define _GNU_SOURCE

#include <fcntl.h>			//Needed for SPI port
#include <sys/ioctl.h>			//Needed for SPI port
#include <linux/spi/spidev.h>		//Needed for SPI port
#include <stdio.h>
#include <stdlib.h>
#include <string.h>
#include <time.h>
#include <sched.h>
#include <sys/mman.h>
#include <bcm2835.h>

int spi_cs0_fd;				//file descriptor for the SPI device
int spi_cs1_fd;				//file descriptor for the SPI device
unsigned char spi_mode;
unsigned char spi_bitsPerWord;
unsigned int spi_speed;

#define MY_PRIORITY (99) /* we use 99 as the PRREMPT_RT use 50
			    as the priority of kernel tasklets
			    and interrupt handler by default */

#define MAX_SAFE_STACK (32*1024) /* The maximum stack size which is
				    guaranteed safe to access without
				    faulting */

#define NSEC_PER_SEC    (1000000000) /* The number of nsecs per sec. */

void rpi_stack_prefault() {
	unsigned char dummy[MAX_SAFE_STACK];
	memset(dummy, 0, MAX_SAFE_STACK);
}

#define PIN_GPIO RPI_V2_GPIO_P1_12	
#define PIN_RESET RPI_V2_GPIO_P1_11
#define OFFSET_GPIO 0
#define OFFSET_RESET 1


struct timespec diff(struct timespec start, struct timespec end)
{
	struct timespec temp;
	if ((end.tv_nsec-start.tv_nsec)<0) {
		temp.tv_sec = end.tv_sec-start.tv_sec-1;
		temp.tv_nsec = 1000000000+end.tv_nsec-start.tv_nsec;
	} else {
		temp.tv_sec = end.tv_sec-start.tv_sec;
		temp.tv_nsec = end.tv_nsec-start.tv_nsec;
	}
	return temp;
}

void clear_pin(uint8_t p){
	bcm2835_gpio_clr_len(p);
	bcm2835_gpio_clr_hen(p);
	bcm2835_gpio_clr_afen(p);
	bcm2835_gpio_clr_fen(p);
	bcm2835_gpio_clr_aren(p);
	bcm2835_gpio_clr_ren(p);
	bcm2835_gpio_set_eds(p);
}

void setup_pin(uint8_t p){
	bcm2835_gpio_fsel(p, BCM2835_GPIO_FSEL_INPT);
	bcm2835_gpio_set_pud(p, BCM2835_GPIO_PUD_UP);

	clear_pin(p);
	//	bcm2835_gpio_fen(p);
}

//*******************************************
//*******************************************
//****************** main *******************
//*******************************************
//*******************************************

uint32_t current=0, voltage=0;
uint8_t gpio=0,avg_count=0;

int main(int argc, char* argv){

	struct timespec r,t,s;
	struct sched_param param;
	int interval = 25000; /* 30us*/

	param.sched_priority = MY_PRIORITY;
	if(sched_setscheduler(0, SCHED_FIFO, &param) == -1) {
		perror("sched_setscheduler failed");
		exit(-1);
	}

	cpu_set_t  mask;
	CPU_ZERO(&mask);
	CPU_SET(3, &mask);
	if (sched_setaffinity(0, sizeof(mask), &mask) )
	{
		perror( "sched_setaffinity failed");
		exit(-3);
	}

	if(mlockall(MCL_CURRENT|MCL_FUTURE) == -1) {
		perror("mlockall failed");
		exit(-2);
	}

	int fd;
	char * myfifo = "/fifo/logger";
//	mkfifo(myfifo, 0666);
//	fd = open(myfifo, O_WRONLY);
	fd = open(myfifo, O_WRONLY | O_CREAT);
	chmod(myfifo, 644);

	if (!bcm2835_init())
		return -5;
	bcm2835_spi_begin();
	bcm2835_spi_setBitOrder(BCM2835_SPI_BIT_ORDER_MSBFIRST);
	bcm2835_spi_setDataMode(BCM2835_SPI_MODE3);
	bcm2835_spi_setClockDivider(BCM2835_SPI_CLOCK_DIVIDER_32);
	bcm2835_spi_chipSelect(BCM2835_SPI_CS0);
	bcm2835_spi_setChipSelectPolarity(BCM2835_SPI_CS0, LOW);

	setup_pin(PIN_GPIO);
	setup_pin(PIN_RESET);
	bcm2835_gpio_fen(PIN_RESET);

	rpi_stack_prefault();

	//	clock_gettime(CLOCK_REALTIME ,&t);

	unsigned char tx_data[] = { 0x82, 0x03, 0x00, 0x00, 0x00, 0x00 }; 
	unsigned char rx_data[sizeof(tx_data)] = { 0x00 }; 
	unsigned char buf[sizeof(rx_data)-2+sizeof(struct timespec)+sizeof(uint8_t)]={0};
	//unsigned char buf[sizeof(rx_data)-2+sizeof(long)]={0};


	clock_gettime(CLOCK_MONOTONIC ,&s);
	s.tv_sec++;
	uint8_t gpio=0;
	uint8_t event=0;

	unsigned long l,delta;
	while(1) {
		clock_nanosleep(CLOCK_MONOTONIC, TIMER_ABSTIME, &s, NULL);
		clock_gettime(CLOCK_REALTIME ,&t);
		bcm2835_spi_transfernb(tx_data,rx_data,sizeof(tx_data));
		if (bcm2835_gpio_eds(PIN_RESET))
		{                                                
			bcm2835_gpio_set_eds(PIN_RESET);
			event=1;
		} else{

		}
		/*if (bcm2835_gpio_eds(PIN_GPIO))
		  {                                                
		  bcm2835_gpio_set_eds(PIN_GPIO);
		  gpio|=1<<OFFSET_GPIO;
		  } else{
		  gpio&=~(1<<OFFSET_GPIO);
		  }*/
		gpio=0|(bcm2835_gpio_lev(PIN_GPIO)<<OFFSET_GPIO)|(bcm2835_gpio_lev(PIN_RESET)<<OFFSET_RESET);
		gpio|=(event<<2);

		uint16_t c=(rx_data[2]<<8)|rx_data[3];
		uint16_t v=(rx_data[4]<<8)|rx_data[5];

                current+=c;
                voltage+=v;                

                avg_count++;
		if(avg_count>=5){
                        uint16_t a_voltage=voltage/avg_count;
                        uint16_t a_current=current/avg_count;
			//bcm2835_delayMicroseconds(2);
			//memcpy(buf,rx_data+2,sizeof(rx_data)-2);
			memcpy(buf,&a_current,sizeof(uint16_t));
			memcpy(buf+sizeof(uint16_t),&a_voltage,sizeof(uint16_t));
			memcpy(buf+2*sizeof(uint16_t),&(gpio),sizeof(uint8_t));
			memcpy(buf+2*sizeof(uint16_t)+sizeof(uint8_t),&(t),sizeof(struct timespec));

			//memcpy(buf+sizeof(rx_data)-2,&(t.tv_nsec),sizeof(long));
			write(fd, buf, sizeof(buf));
			event=0;
                        avg_count=0;
                        current=0;
                        voltage=0;
		}
		s.tv_nsec += interval;
		while (s.tv_nsec >= NSEC_PER_SEC) {
			s.tv_nsec -= NSEC_PER_SEC;
			s.tv_sec++;
		}
		r.tv_nsec=t.tv_nsec;
		r.tv_sec=r.tv_sec;
		/*
		   if(t.tv_nsec>l){
		   delta=t.tv_nsec-l;
		   if(delta>100000L)
		   printf("%lu\n",delta);
		   }
		   l=t.tv_nsec;
		 */
	}
	bcm2835_spi_end();
	bcm2835_close();

}

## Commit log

2017-01-09 initial commit for public repo
    [d-cube.brd, d-cube.sch]
2019-04-19 Update to 2.1
    [d-cube.brd, d-cube.sch]

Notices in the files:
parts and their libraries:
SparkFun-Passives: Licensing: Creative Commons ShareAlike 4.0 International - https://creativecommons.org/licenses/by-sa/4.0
